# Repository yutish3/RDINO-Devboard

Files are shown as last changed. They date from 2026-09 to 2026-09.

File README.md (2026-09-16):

# Rdino - 2040
rp-2040 development board in the shape of arduino uno r3 so it supports its hats and also has esp32 for wifi and bluetooth and 5x5 grid of neo pixel leds



Journal 1	:- 2.0 hours

Journal 2	:- 1.5 hours

Journal 3	:- 0.4 hours

Journal 4	:- 1.5 hours

Journal 5	:- 1.0 hours

Journal 6	:- 1.5 hours

Journal 7	:- 1.3 hours

Journal 8	:- 2.0 hours

Journal 9	:- 1.0 hours

Journal 10	:- 0.5 hours

Journal 11	:- 2.0 hours

Journal 12	:- 2.5 hours

Journal 13	:- 2.0 hours

Journal 14	:- 5.2 hours

Journal 15	:- 1.0 hours

Journal 16	:- 0.5 hours

Journal 17	:- 0.5 hours

Journal 18	:- 5.5 hours

Journal 19	:- 2.0 hours

Journal 20	:- 3.0 hours

## VISION
main goals I had was making it is that I wanted to have a powerful board on which Arduino hats can fit with wireless capabilities so I used both rp 2040 and esp 32 and connected gpios of both so rp 2040 can off load some tasks to esp 32. so in a sense it is like Arduino UNO but on steroids 

and for usage too it can be used like a normal Arduino UNO 

it has dual microcontroller so all the less important repetative tasks can be off loaded to esp32 and main work can be done by the rp 2040 chip with extra 16M bit memory
and it can be used foor any project like lfr robot , micromouse , rc car etc

## what makes it special (main components)
&#9679; RP2040 :- main microcontroller

&#9679; W25Q128JVS :- 128Mbit Flash Memory for extra juice

&#9679; ESP32-C3-WROOM-02 :- backup microcontroller with wifi and Bluetooth capabilities 

&#9679; 25 X WS2812B-2020 :- programmable rgb leds

## Images















| Component | Purpose | Qty | Cost (INR) | Distributor |
| --- | --- | --- | --- | --- |
| RP2040 (QFN-56) | Main Microcontroller | 1 | ₹81.00 | [Evelta](https://evelta.com/rp2040-264kb-sram-dual-arm-cortex-m0-processor-mcu-by-raspberry-pi/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) |
| ESP32-C3-WROOM-02 | Wi-Fi / BLE Module | 1 | ₹312 | [Evelta](https://evelta.com/esp32-c3-wroom-02-n4-wi-fi-ble-module-4mb-flash-pcb-antenna/?sku=136-ESP32-C3-WROOM-02-N4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) |
| W25Q128JVS (SOIC-8) | 128Mbit Flash Memory | 1 | ₹223 | [Evelta](https://evelta.com/serial-nor-flash-memory-128mbit-8pin-soic/?sku=153-W25Q128JVSIQ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) |
| AP2112K-3.3 (SOT-23-5) | 3.3V LDO Voltage Regulator | 1 | ₹24 | [Evelta](https://evelta.com/linear-voltage-regulator-positive-fixed-1-output-300ma-ic-sot-23-5/?sku=035-TLV74033PDBVR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) |
| WS2812B-2020 (PLCC4) | Addressable RGB LEDs (D1-D24, D27, D29, D31) | 25 | ₹275 | [Robu](https://robu.in/product/1-month-warranty-953/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) |
| 74AHCT125 | 3.3v to 5v converter | 1 | ₹113 | [Lioncircuit](https://www.lioncircuits.com/parts/74AHCT125PW%2C118) |
| Standard LED (0603) | Status Indicator (D26) | 1 | ₹3.3 | [evelta](https://evelta.com/0603-orange-chip-led/?srsltid=AfmBOopJK48IT0WFYCzFETDcCPIIkiPRop17X2j5vajIVfQTBZ31vxPa) |
| USB-C Receptacle 14-Pin | Power and Data Interface (J1) | 1 | ₹8 | [Hubtronics](https://hubtronics.in/usb-type-c-16p-female-connector-surface-mount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) |
| 1x04 Pin Header/Socket | I/O Expansion / Programming (J6) | 1 | ₹11 | [Robu](https://robu.in/product/fh2-0-09-04pzd-xunpu-plugin1x4-pin-2mm-female-headers-rohs/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)|
| 1x06 Pin Header/Socket | I/O Expansion (J2) | 5 | ₹53 | [Robu](https://robu.in/product/6-pin-female-11mm-tall-stackable-header-connector-for-arduino-5pcs/) |
| 1x08 Pin Header/Socket | I/O Expansion (J4, J5) | 2 | ₹32 | [Robu](https://robu.in/product/fh1-27-01-08pzd-xunpu-plugin1x8-pin-1-27mm-female-headers-rohs/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) |
| 1x10 Pin Header/Socket | I/O Expansion (J3) | 1 | ₹17 | [Robu](https://robu.in/product/fh1-27-01-10pzd-xunpu-plugin1x10-pin-1-27mm-female-headers-rohs/) |
| Push Button (KMR2) | Reset / User Input (SW1, SW2) | 2 | ₹126 | [Robu](https://robu.in/product/kmr221nglfs-ck-2-8mm-0-5mm-round-button-50ma-vertical-welding-4-2mm-spst-2n-32v-smd-tactile-switches-rohs/) |
| 1.1kΩ Resistor (0603) | Current Limiting / Pull-up | 1 | ₹1 | [Robu](https://robu.in/product/0603waj0112t5e-uniohm-royal-ohm-100mw-thick-film-resistors-75v-%C2%B1100ppm-%E2%84%83%C2%B15-1-1k%CF%89-0603-chip-resistor-surface-mount-rohs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) |
| 4.7kΩ Resistor (0603) | I2C / General Pull-up | 2 | ₹5 | [Robu](https://robu.in/product/rt0603brd074k7l-yageo-res-thin-film-0603-4-7k-ohm-0-1-0-1w1-10w-%C2%B125ppm-c-pad-smd-t-r/) |
| 10kΩ Resistor (0603) | Pull-up / Pull-down | 3 | ₹3 | [Robu](https://robu.in/product/10k-ohm-1-4w-0603-surface-mount-chip-resistor-pack-of-100/) |
| 5.1kΩ Resistor (0603) | USB-C CC line Pull-down | 2 | ₹3 | [Robu](https://robu.in/product/rt0603fre075k1l-yageo-100mw-thin-film-resistor-75v-%C2%B150ppm-%E2%84%83-%C2%B11-5-1k%CF%89-0603-chip-resistor-surface-mount-rohs/) |
| 1μF Capacitor (0603) | Decoupling / Bypass | 6 | ₹8.5 | [Robu](https://robu.in/product/1uf-1000nf-50v-capacitor-0603-smd-package-pack-of-20/) |
| 10pF Capacitor (0603) | Crystal Load Capacitors | 2 | ₹1 | [Robu](https://robu.in/product/10pf-0603-surface-mount-multilayer-ceramic-capacitor-pack-of-50/) |
| Crystal 3225 (4-Pin) | Clock Source for RP2040 (Y1) | 1 | ₹101 | [lion circuit](https://www.lioncircuits.com/parts/NX3225SA-12MHZ-STD-CSR-6) |
| PCB | PCB | 1 | ₹3375 | [Robu] |
| Hot plate | soldering | 1 | ₹2,749 | [Amazon](https://www.amazon.in/Preheating-Soldering-Preheater-Platform-56x56x35mm/dp/B0C7W3W8C4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) |
| soldering flux | gooye paste to combine components | 1 | ₹400 | [amazon](https://www.amazon.in/Electron-Soldering-Syringe-No-Clean-Electronics/dp/B0GTMJHBJ4) |

The Bare Components : ₹1,708.80

PCB Fabrication (Robu): ₹3,375.00

Assembly Tools (Amazon): ₹3,262.00

Grand Total: ₹8,345.8

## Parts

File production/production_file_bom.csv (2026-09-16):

Designator | Footprint | Quantity | Value | LCSC Part #
C1, C2 | 0201 | 2 | 15pF
C10, C11, C12, C14, C15, C16, C17, C18, C19, C20, C21, C22, C23, C24, C25, C26, C27, C28, C29, C30, C31, C32, C33, C34, C35, C36, C37, C38, C39, C40, C41, C42, C43, C44, C45 | 0201 | 35 | 0.1uF
C13 | 0201 | 1 | 470μF
C3, C4, C5, C6, C7, C8, C9 | 0201 | 7 | 1uF
D1, D10, D11, D12, D13, D14, D15, D16, D17, D18, D19, D2, D20, D21, D22, D23, D24, D25, D3, D4, D5, D6, D7, D8, D9 | LED_WS2812B-2020_PLCC4_2.0x2.0mm | 25 | WS2812B-2020
D26 | 0603 | 1 | LED
J1 | USB_C_Receptacle_HRO_TYPE-C-31-M-12 | 1 | USB_C_Receptacle_USB2.0_14P
J2 | PinSocket_1x06_P2.54mm_Vertical | 1 | Conn_01x06
J3 | PinSocket_1x10_P2.54mm_Vertical | 1 | Conn_01x10
J4, J5 | PinSocket_1x08_P2.54mm_Vertical | 2 | Conn_01x08
J6, J7 | PinHeader_1x04_P2.54mm_Vertical | 2 | Conn_01x04
R1, R2 | 0201 | 2 | 5.1K
R10, R9 | 0201 | 2 | 27
R11, R3 | 0201 | 2 | 1K
R12, R4, R5, R6 | 0201 | 4 | 10K
R13 | 0201 | 1 | 330
SW1, SW2 | SW_Push_1P1T_NO_CK_KMR2 | 2 | SW_Push
SW3 | SW_Push_1P1T_NO_CK_KMR2 | 1 | ESP_BOOT
SW4 | SW_Push_1P1T_NO_CK_KMR2 | 1 | ESP_RST
U1 | QFN-56-1EP_7x7mm_P0.4mm_EP3.2x3.2mm | 1 | RP2040
U2 | SOIC-8_5.3x5.3mm_P1.27mm | 1 | W25Q128JVS
U3 | SOT-23-5 | 1 | AP2112K-3.3
U4 | TSSOP-14_4.4x5mm_P0.65mm | 1 | 74AHCT125
U5 | ESP32-C3-WROOM-02 | 1 | ESP32-C3-WROOM-02
Y1 | Crystal_SMD_3225-4Pin_3.2x2.5mm | 1 | 12MHz

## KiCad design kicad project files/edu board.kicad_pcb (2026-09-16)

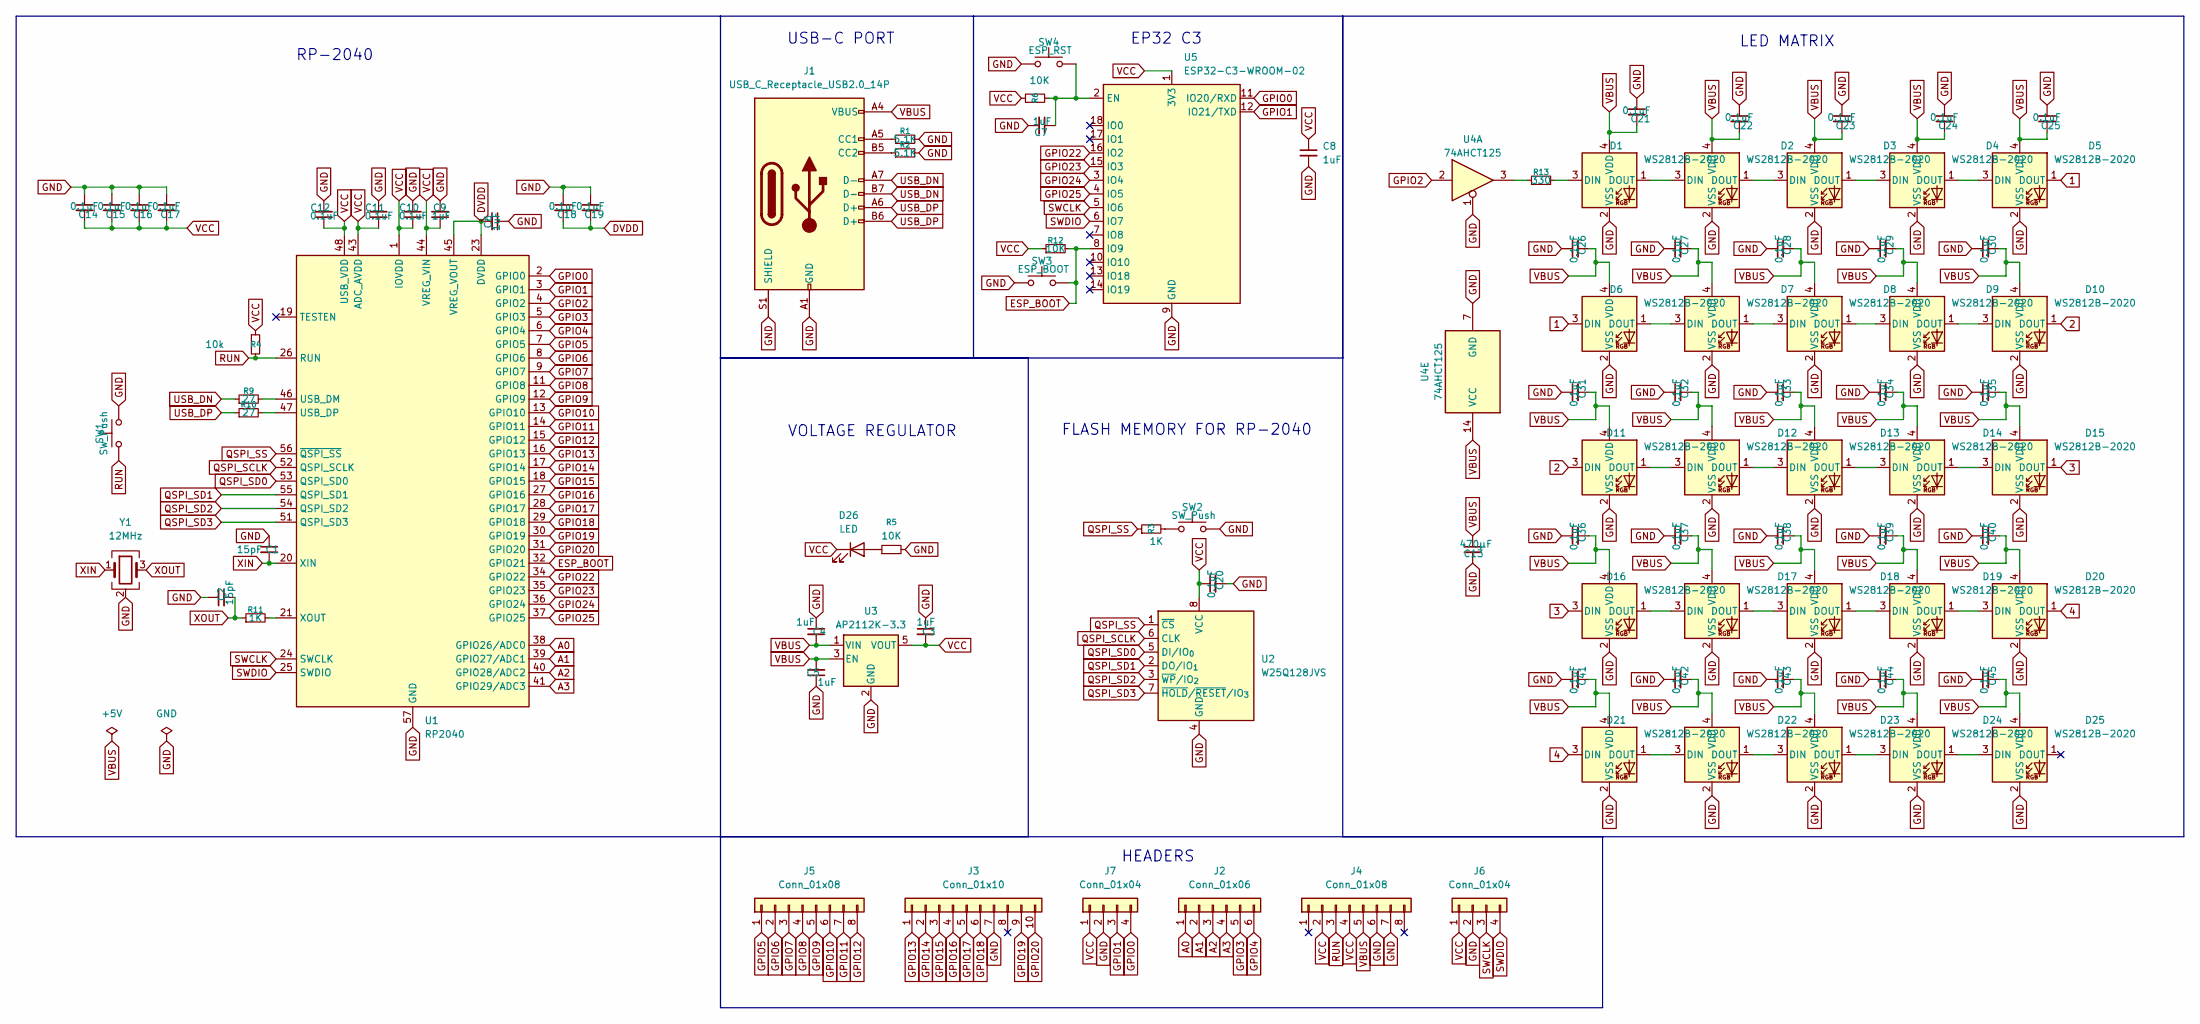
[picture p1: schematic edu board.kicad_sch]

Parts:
C1, C2: 15pF; C_0201_0603Metric
C3, C4, C5, C6, C7, C8, C9: 1uF; C_0201_0603Metric
C10, C11, C12, C14, C15, C16, C17, C18, C19, C20, C21, C22, C23, C24, C25, C26, C27, C28, C29, C30, C31, C32, C33, C34, C35, C36, C37, C38, C39, C40, C41, C42, C43, C44, C45: 0.1uF; C_0201_0603Metric
C13: 470μF; C_0201_0603Metric
D1, D2, D3, D4, D5, D6, D7, D8, D9, D10, D11, D12, D13, D14, D15, D16, D17, D18, D19, D20, D21, D22, D23, D24, D25: WS2812B-2020; LED_WS2812B-2020_PLCC4_2.0x2.0mm
D26: LED; LED_0603_1608Metric
J1: USB_C_Receptacle_USB2.0_14P; USB_C_Receptacle_HRO_TYPE-C-31-M-12
J2: Conn_01x06; PinSocket_1x06_P2.54mm_Vertical
J3: Conn_01x10; PinSocket_1x10_P2.54mm_Vertical
J4, J5: Conn_01x08; PinSocket_1x08_P2.54mm_Vertical
J6, J7: Conn_01x04; PinHeader_1x04_P2.54mm_Vertical
R1, R2: 5.1K; R_0201_0603Metric
R3, R11: 1K; R_0201_0603Metric
R4: 10k; R_0201_0603Metric
R5, R6, R12: 10K; R_0201_0603Metric
R9, R10: 27; R_0201_0603Metric
R13: 330; R_0201_0603Metric
SW1, SW2: SW_Push; SW_Push_1P1T_NO_CK_KMR2
SW3: ESP_BOOT; SW_Push_1P1T_NO_CK_KMR2
SW4: ESP_RST; SW_Push_1P1T_NO_CK_KMR2
U1: RP2040; QFN-56-1EP_7x7mm_P0.4mm_EP3.2x3.2mm
U2: W25Q128JVS; SOIC-8_5.3x5.3mm_P1.27mm
U3: AP2112K-3.3; SOT-23-5
U4: 74AHCT125; TSSOP-14_4.4x5mm_P0.65mm
U5: ESP32-C3-WROOM-02
Y1: 12MHz; Crystal_SMD_3225-4Pin_3.2x2.5mm

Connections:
1: D5.1 (DOUT), D6.3 (DIN)
2: D10.1 (DOUT), D11.3 (DIN)
3: D15.1 (DOUT), D16.3 (DIN)
4: D20.1 (DOUT), D21.3 (DIN)
A0: J2.1, U1.38 (GPIO26/ADC0)
A1: J2.2, U1.39 (GPIO27/ADC1)
A2: J2.3, U1.40 (GPIO28/ADC2)
A3: J2.4, U1.41 (GPIO29/ADC3)
DVDD: C6.2, C18.2, C19.2, U1.23 (DVDD), U1.45 (VREG_VOUT), U1.50 (DVDD)
ESP_BOOT: R12.2, SW3.2, U1.32 (GPIO21), U5.8 (IO9)
GND: C1.1, C2.1, C3.1, C4.1, C5.1, C6.1, C7.2, C8.2, C9.2, C10.2, C11.2, C12.2, C13.2, C14.1, C15.1, C16.1, C17.1, C18.1, C19.1, C20.2, C21.1, C22.1, C23.1, C24.1, C25.1, C26.1, C27.1, C28.1, C29.1, C30.1, C31.1, C32.1, C33.1, C34.1, C35.1, C36.1, C37.1, C38.1, C39.1, C40.1, C41.1, C42.1, C43.1, C44.1, C45.1, D1.2 (VSS), D2.2 (VSS), D3.2 (VSS), D4.2 (VSS), D5.2 (VSS), D6.2 (VSS), D7.2 (VSS), D8.2 (VSS), D9.2 (VSS), D10.2 (VSS), D11.2 (VSS), D12.2 (VSS), D13.2 (VSS), D14.2 (VSS), D15.2 (VSS), D16.2 (VSS), D17.2 (VSS), D18.2 (VSS), D19.2 (VSS), D20.2 (VSS), D21.2 (VSS), D22.2 (VSS), D23.2 (VSS), D24.2 (VSS), D25.2 (VSS), J1.A1 (GND), J1.A12 (GND), J1.B1 (GND), J1.B12 (GND), J1.S1 (SHIELD), J3.7, J4.6, J4.7, J6.2, J7.2, R1.2, R2.2, R5.2, SW1.2, SW2.2, SW3.1, SW4.1, U1.57 (GND), U2.4 (GND), U3.2 (GND), U4.1, U4.7 (GND), U5.9 (GND), U5.19 (GND), Y1.2 (G), Y1.4 (G)
GPIO0: J7.4, U1.2 (GPIO0), U5.11 (IO20/RXD)
GPIO1: J7.3, U1.3 (GPIO1), U5.12 (IO21/TXD)
GPIO2: U1.4 (GPIO2), U4.2
GPIO3: J2.5, U1.5 (GPIO3)
GPIO4: J2.6, U1.6 (GPIO4)
GPIO5: J5.1, U1.7 (GPIO5)
GPIO6: J5.2, U1.8 (GPIO6)
GPIO7: J5.3, U1.9 (GPIO7)
GPIO8: J5.4, U1.11 (GPIO8)
GPIO9: J5.5, U1.12 (GPIO9)
GPIO10: J5.6, U1.13 (GPIO10)
GPIO11: J5.7, U1.14 (GPIO11)
GPIO12: J5.8, U1.15 (GPIO12)
GPIO13: J3.1, U1.16 (GPIO13)
GPIO14: J3.2, U1.17 (GPIO14)
GPIO15: J3.3, U1.18 (GPIO15)
GPIO16: J3.4, U1.27 (GPIO16)
GPIO17: J3.5, U1.28 (GPIO17)
GPIO18: J3.6, U1.29 (GPIO18)
GPIO19: J3.9, U1.30 (GPIO19)
GPIO20: J3.10, U1.31 (GPIO20)
GPIO22: U1.34 (GPIO22), U5.16 (IO2)
GPIO23: U1.35 (GPIO23), U5.15 (IO3)
GPIO24: U1.36 (GPIO24), U5.3 (IO4)
GPIO25: U1.37 (GPIO25), U5.4 (IO5)
unnamed: D1.3 (DIN), R13.2
unnamed: D1.1 (DOUT), D2.3 (DIN)
unnamed: D2.1 (DOUT), D3.3 (DIN)
unnamed: D3.1 (DOUT), D4.3 (DIN)
unnamed: D4.1 (DOUT), D5.3 (DIN)
unnamed: D6.1 (DOUT), D7.3 (DIN)
unnamed: D7.1 (DOUT), D8.3 (DIN)
unnamed: D8.1 (DOUT), D9.3 (DIN)
unnamed: D9.1 (DOUT), D10.3 (DIN)
unnamed: D11.1 (DOUT), D12.3 (DIN)
unnamed: D12.1 (DOUT), D13.3 (DIN)
unnamed: D13.1 (DOUT), D14.3 (DIN)
unnamed: D14.1 (DOUT), D15.3 (DIN)
unnamed: D16.1 (DOUT), D17.3 (DIN)
unnamed: D17.1 (DOUT), D18.3 (DIN)
unnamed: D18.1 (DOUT), D19.3 (DIN)
unnamed: D19.1 (DOUT), D20.3 (DIN)
unnamed: D21.1 (DOUT), D22.3 (DIN)
unnamed: D22.1 (DOUT), D23.3 (DIN)
unnamed: D23.1 (DOUT), D24.3 (DIN)
unnamed: D24.1 (DOUT), D25.3 (DIN)
unnamed: D26.2 (A), R5.1
unnamed: J1.A5 (CC1), R1.1
unnamed: J1.B5 (CC2), R2.1
unnamed: R3.2, SW2.1
unnamed: R13.1, U4.3
unnamed: R9.2, U1.46 (USB_DM)
unnamed: R10.2, U1.47 (USB_DP)
unnamed: R11.2, U1.21 (XOUT)
unnamed: C7.1, R6.2, SW4.2, U5.2 (EN)
QSPI_SCLK: U1.52 (QSPI_SCLK), U2.6 (CLK)
QSPI_SD0: U1.53 (QSPI_SD0), U2.5 (DI/IO_{0})
QSPI_SD1: U1.55 (QSPI_SD1), U2.2 (DO/IO_{1})
QSPI_SD2: U1.54 (QSPI_SD2), U2.3 (~WP/IO_{2})
QSPI_SD3: U1.51 (QSPI_SD3), U2.7 (~HOLD/~RESET/IO_{3})
QSPI_SS: R3.1, U1.56 (~QSPI_SS), U2.1 (~CS)
RUN: J4.3, R4.2, SW1.1, U1.26 (RUN)
SWCLK: J6.3, U1.24 (SWCLK), U5.5 (IO6)
SWDIO: J6.4, U1.25 (SWDIO), U5.6 (IO7)
USB_DN: J1.A7 (D-), J1.B7 (D-), R9.1
USB_DP: J1.A6 (D+), J1.B6 (D+), R10.1
VBUS: C4.2, C5.2, C13.1, C21.2, C22.2, C23.2, C24.2, C25.2, C26.2, C27.2, C28.2, C29.2, C30.2, C31.2, C32.2, C33.2, C34.2, C35.2, C36.2, C37.2, C38.2, C39.2, C40.2, C41.2, C42.2, C43.2, C44.2, C45.2, D1.4 (VDD), D2.4 (VDD), D3.4 (VDD), D4.4 (VDD), D5.4 (VDD), D6.4 (VDD), D7.4 (VDD), D8.4 (VDD), D9.4 (VDD), D10.4 (VDD), D11.4 (VDD), D12.4 (VDD), D13.4 (VDD), D14.4 (VDD), D15.4 (VDD), D16.4 (VDD), D17.4 (VDD), D18.4 (VDD), D19.4 (VDD), D20.4 (VDD), D21.4 (VDD), D22.4 (VDD), D23.4 (VDD), D24.4 (VDD), D25.4 (VDD), J1.A4 (VBUS), J1.A9 (VBUS), J1.B4 (VBUS), J1.B9 (VBUS), J4.5, U3.1 (VIN), U3.3 (EN), U4.14 (VCC)
VCC: C3.2, C8.1, C9.1, C10.1, C11.1, C12.1, C14.2, C15.2, C16.2, C17.2, C20.1, D26.1 (K), J4.2, J4.4, J6.1, J7.1, R4.1, R6.1, R12.1, U1.1 (IOVDD), U1.10 (IOVDD), U1.22 (IOVDD), U1.33 (IOVDD), U1.42 (IOVDD), U1.43 (ADC_AVDD), U1.44 (VREG_VIN), U1.48 (USB_VDD), U1.49 (IOVDD), U2.8 (VCC), U3.5 (VOUT), U5.1 (3V3)
XIN: C1.2, U1.20 (XIN), Y1.1
XOUT: C2.2, R11.1, Y1.3

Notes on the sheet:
USB-C PORT
FLASH MEMORY FOR RP-2040
RP-2040
LED MATRIX
VOLTAGE REGULATOR
EP32 C3
HEADERS

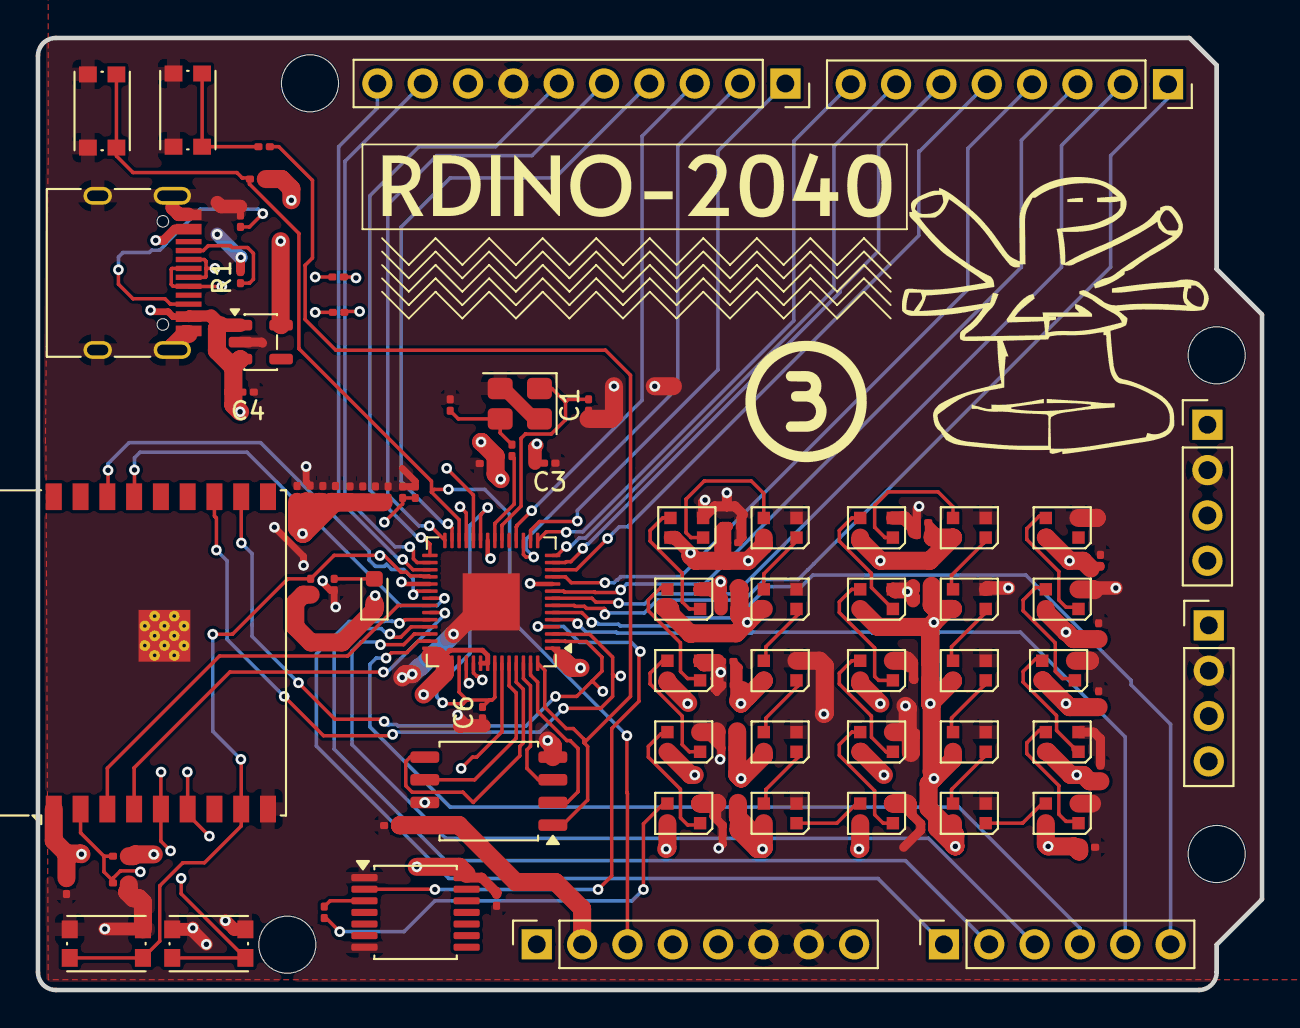
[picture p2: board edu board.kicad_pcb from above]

Board: 4 copper layers, 68.6 x 53.3 mm, 99 parts (0 on the bottom side), 81 nets.

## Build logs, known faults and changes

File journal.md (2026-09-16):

# Journal 1 ( 2 HOURS ) :- initial planing 

the idea is the same as description
things i have decided :-

    it will use rp2040
    16 Mbit flash memory for extra ram (16 mega bit is 4mb )
    bluetooth module (the one used in esp32)
    5x5 neo pixel led grid (coz it looks cool ngl)
    usb c for programing

i selected all the components for each thing all the things i mentioned above and for voltage regulation and got them all into kicad and arranged them into a decent manner also studied arduino uno shape and headers location it has 2 8 and 2 6 female header chains



---

# Journal 2 ( 1.5 HOURS ) :- made schematic of power system 

so how this power system works is the whole board works on usb c and from usb c the power goes to AP2112K-3.3 which converts the 5v into 3.3v which we will use to power almost the entire board except neo pixels which require 5v so for them i will connect them directly to VBUS(5V) instead of VCC(3.3V) and the crystal oscilator is used for syncronising the rp2040 chip to other signals i also placed the power and gnd flags in start i learned it from my last project 



---

# Journal 3 ( 0.4 HOURS ) :- completed the wiring for buttons and esp 32 wifi 

completed the wiring esp 32 wifi and 2 buttons 1 for reset the board and 1 for running the board which completes a major part of the schematic process





---

# Journal 4 ( 1.5 HOURS ) :- completed the schematics 

99.9% of the schematic is complete (not 100% coz there could be smth i might have forgotten )

i did the schematic of esp32 (will use wifi and bluetooth from it) and as there is a light weight esp32 present i connected left over digital pins to it so people can use its processing power in background



i also did the wiring of pins like in an arduino uno R3 



the extra thing is for display

completed the schematic of extra mbit flash memory 



also added in data lines for usb c port

oo yea i forgot i still have to select the footprints and fix erc

which uhh :( , might take some time so its only 80% complete and most time consuming and pain work starts now




also did the schematic of all the neo leds 



---

# Journal 5 ( 1 HOURS ) :- fixed all the errors and added in footprints 

fixed all the errors and added in footprints errors were mainly being pins not connected to anything and me applying wrong pwr_flag







---

# Journal 6 ( 1.5 HOURS ) :- started with pcb design 

first i got the laybout and size of the arduino uno r3 then i added in both planes to automatically fill up all the ground plane connections and then first placed the female headers exactly where and how they are placed in uno and then places rest of the components

resistors were pretty easy to figure out where to place because of shorter connection the better but for capacitors they were like VBUS and GND only so connections can be every hwere so i had to go back to schematic find the exact capacitor and place it as close as i can in pcb to the part it is connected to





i still have a really big open area where i will prob add a bunch of art of smth like that also

---

# Journal 7 ( 1.3 HOURS ) :- gpio pins done of female headers 

firstly i made 2 more planes one for gnd and one for power management and i also added in net classes and increased constraints so there will be no problem eben if it is made offline then i did the routing of gpio pins of female headers and i also plan it to submit to kicad competition so i am trying to make as clean of routing as possible (also the reason why i increased some constraints )











---

# Journal 8 ( 2 HOURS ) :- routing almost completed 

first thing 1st i made 2nd plane as vcc so it made routing a little easier and added patches of vbus in it to make vbus also a little easier (i also passed the data lines through it to make it a little more easier as they needed to be length matched which i also did )

the length match is so perfect the difference between the length of power lines is 0.08mm

i also did routing of other components





i initially though of writing it journal once the whole routing process is complete but i did now because i just realised that the arrangement of neo leds is wrong and i can really route them easily i will have to use 2 planes and i think i would preffer to delete the current routing and rearrange them

---

# Journal 9 ( 1 HOURS ) :- fixed the neo pixel led routing 



fixed the neo pixel leds and a little more routes here and there

the neo pixel arrangement and routing looks so good i love it 



adding it extra time to avoid a huge mess and make the routing look cool was so worth it

---

# Journal 10 ( 0.5 HOURS ) :- completed the routing 

firstly i completed all the routing that was left (except 3 that are interconnecting i will have to switch from schematic kinda making a x with triple line )

and removed all the text of value and number of capacitor and resistor and all the components so it will look a little bit better



i also ran drc check and emm ahh what do i say 



it will prob take me a while

---

# Journal 11 ( 2 HOURS ) :- fixed all the errors and a bit of designing 

first i had to deal with errors some were caused because of text on routing some were because of missed routing or traces i accidently deleated or some were because of clearance being too big which was my bad and some were because planes werent connected like gnd and 5v ( i mean small patches on that plane that werent connected to the main patch )

i selected each one did hit and trial and somehow stuff worked out

i also spent time learning and designing the board to make it look cool i wanted to add hack club dino svg but i couldnt find it

i will ask on slack if i could find and submit with that in final design

also 3 warnings that are left are of no issues







---

# Journal 12 ( 2.5 HOURS ) :- finalization 

while i was getting 3d render of the board i realised the usb c port was in the wrong direction so i had to go back to the pcb design rotate the usb c 180 degree and do all the routing of it again ( i switched tags of + data line and - data line in schematic because it was making a x so it was making it much harder to route. i also length matched them again) then i fixed all the erc errors because of left out routes and that small patch thing not connected to big patch

then i did some changes in the design by changing location of the rp - 2040 thoese lines and 3 and adding in dino

then i decided to import 3d model of the parts that werent visible in the 3d viewer i got them online imported them and for some reason importing the 3d model once for neo led wouldnt make it so that all of them automatically import that 3d model, so i had to manually select each one and upload the 3d model to it

then i decided to change the colour of the pcb to black because it looks better in my opinion and then i took some render images of it

then i made a banner for it that i applied above ( this one took me a while because i didt knew the scale of the banner and i wanted it to be perfect so i just did some hit and trial until it worked)

and final thing last i made the github repo of then entire project





---

# Journal 13 ( 2 HOURS ) :- selected components and found more problems 

i started by selecting main components rp2040 , esp 32 wroom2 , W25Q128JVS , AP2112K-3.3 , WS2812B-2020 then i noticed that the led needs 5v to run which i have already given it but the input was coming from rp2040 which is 3.3v so i had to add 74AHCT125 and select component for that too and i checked all the pins , footprint and read their datasheets to find if i had any thing that i missed and i also updated the github BOM but then while routing 74AHCT125 i noticed all the traces are of equal length then i noticed that in board setup up i did setup the net classes but i named them 3v3 and 5v instead of VBUS and VCC also i wrote YSB_DN and its pretty embarrassing ngl



so i tweaked the setup a bit fixed it and when i applied them umm i got 187 errors 





---

# Journal 14 ( 5.2 HOURS ) :- fixing mistakes 

i went through every single error and warning earlier there were



problems like this all over the board i had to add a lot of trace width 



and then when i was fixing i used the new trace width and whenever i encountered a point where i couldn't use the default ones i set i went from the top to bottom of these ones i added until i found the one which perfectly fits trying to making them as thick and possible and as short as possible at the same time to make them short i used the trick called fan out where i made a short trace (i tried to make it shorter then 50mils) which then connects to a thicker trace or a via

also i had to again length match the usb c data lines again and they only have a difference of 4 mils now

and here is what final pcb looks like 







this part took me 3.2 hr

the more i am reading my journals the more mistakes i am finding 



why did i use resistor footprints for capacitor i prob just went with the flow and spam clicked the button



why did i legit thought they go in opposite direction like + with - and - with +

i think i should get a rubber ducky to explain everything i did

ig i wasnt reading datasheets that often or not with much attention







also i length matched them they both are 1742 mils now 



i also got hit by 5 errors and 9 warning i also went around the whole pcb remove all the small text things i forgot what they were called like u5 etc and values of capacitor i removed all of them and fixed all the issues with the pcb"

and finally i selected all the components (the buttons are lowkey expensive like way expensive then i thought i tried finding an alternative but these ones are the perfect match)

this part took me 2 hrs

i accidentally missed a journal while transferring so i had to merge these together

---

# Journal 15 ( 1 HOURS ) :- pretty much complete 

i tried finding a crystal ossicator that will work with rp2040 based on my current footprint and i found an high quality one but it has load capacitance of 8 pF so i was to switch the capacitors to 10pF (if i am wrong then correct me the formula is c = 2 x (load capacitance - stray capacitance) so c = 2 x (8 - 3) , c = 10 ) 



so yea it was a quick fix for it no need to change anything in schematic or footprint i did check the datasheet and its pretty vague it does tell about 2 and 4 being gnd but not about other pins but usually all 4 pin ones have the same pins so ill take a gamble with this one

---

# Journal 16 ( 0.5 HOURS ) :- final list 

i am making final adjustments and changes before submitting for grant 



ROBU CART 







Evelta cart 







lion circuit cart 





robu pcb 









---

# Journal 17 ( 0.5 HOURS ) :- fixing all the errors

(my project got reviewed on forge and this is what they said :- You are missing all of your decoupling capacitors. There may be a brownout during operation. Also, i noticed that you name the values of your passives as "__1 __2 ..." Please don't do that because kicad will treat them as separate components, which is not the best practice. For future projects, please follow general conventions for your schematic since it is very hard to read.)

thanks for such a great overview a lot of things went over my head and i messed up some things so i am really thankful that you told me every reason my board would have failed it advanced i will also be going through the datasheets of chips etc to see if i missed anything else

so imma first start with fixing all the resistors and capacitor and led names 





changed these to this 



i am also verifying that capacitors are near the component they are placed for or not 



and i noticed there is a lot of gap in some capacitors c4 is close but c3 and c5 are really far 



and i need to have more resistors and capacitors for usb and rp2040 chip i am also reading and re checking everything in hardware design 2040 pdf i will have to add 



in next journal

---

# Journal 18 ( 5.5 HOURS ) :- fixing and rechecking everything

i am point point by point of hardware designn of rp2040 and checking and fixing everything first was input supply which was already correct 



second was Decoupling capacitors so i added as much as the guide said 3 are connected directly and 4 will be placed close to those 3 this should help in having less interference 



third was internal voltage regulator that is shown in above screenshot

fourth was flash storage which was fine already i just have to add a capacitor 





i also moved the switch a bit close in the schematic which will be used to force the RP2040 into USB mass storage mode

a bit later i realized io3 and 0 were swapped so i fixed it 



fifth was crystal oscillator in this i first added the value of it and then changed the value of capacitors from 10 to 15pF and added in the resistor 



also while making this i had to recheck it a few times because initially i made the mistake of connecting capacitor to rp2040 instead of between xout pin resistor

sixth was USB and it was correct before hand 





sevent were io pins and most of it was fine i fixed swd added in uart (earlier i had uart tags on esp 32 but on on the headers) and i also added in switches needed to put esp 32 into boot mode 





so now i have 3 ways to code rp2040 chip 1 usb c port 2 swd 3 uart

quick thing i checked which had an error was esp 32 c3 's boot pin is actually io9 so i moved the tag a bit



i also fixed the led matrix 





added in a big capacitor of 470μF and small capacitor for each leds

and this is where the main parts of the document ends i rechecked everything and it should work just fine

i also fixed 2 erc errors i had both were because of pins not having X tag 





idk about the warnings ill try to find what each warning means

---
## i made a small rpp-2040 dev board in between and i learnt a bit and used footprints i have never used before and overall even though the dev board was rushed i still learnt a lot and its been a month since i made this project so i will quickly complete it now 

# Journal 19 ( 2 HOURS ) :- cleaned up the schematic 
firstly i changed the footprints to smaller ones





then i perfectly cleaned up the schematics 



now i have to do the routing part 





# Journal 20 ( 3 HOURS ) :- fixed all the errors in the pcb and fixed its looks
because i added in so many capacitors i had to make space for them and every leds had its own capacitor so i had to cram them up

and a lot of times kicad was throwing in errors that traces are too close etc also adding in 2nd layer payed off as i was able to make area for everything on there when there was no way to route it


earlier me would have had to reroute the whole thing but i managed to do it quite easily it was just pain doing it and this marks the end of this project.
